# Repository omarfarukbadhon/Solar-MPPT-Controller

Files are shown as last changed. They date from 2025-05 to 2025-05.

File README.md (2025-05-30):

# Design and Development of a 1.5A MPPT Solar Charge Controller! 
Built around the LT3652, this compact system is optimized for 15W solar panels and 12V SLA batteries, offering efficient 3-stage charging with enhanced thermal and electrical protection.
Designed for harsh environments with: <br> 
✅ Reverse polarity and surge protection <br> 
✅ DIN-rail mountable compact PCBA (75×55 mm)

# 3D View of Solar MPPT Charge controller design 



# PCB Routing 



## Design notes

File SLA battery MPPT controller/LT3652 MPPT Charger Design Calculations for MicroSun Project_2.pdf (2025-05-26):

LT3652 MPPT Charger Design Calculations for MicroSun Project

### 1. Project Overview

This document outlines the design calculations for configuring the LT3652-based MPPT solar battery charger, targeting a 12V SLA battery and a 15W solar panel.

### 2. Charging Current Sense Resistor (R_SENSE)

Objective: Limit charging current to 1.5A maximum.

Formula:

R_SENSE = 0.1 / I_CHG(MAX)

Calculation:

R_SENSE = 0.1 / 1.5 = 0.0667 ohms

Recommended: Use standard value 0.068 ohm, 1% tolerance, ≥0.5W rated, low TCR.

### 3. How These Feedback Resistor Values Were Chosen (with LM234)

From the datasheet (Figure 9b), they used this design procedure:

Given:

- TC (temperature coefficient) = −19.8 mV/°C
- V_FLOAT (25°C) = 13.8 V
- R_SET = 2.4 kΩ for LM234
Step 1: Compute R_FB1

R_FB1 = −R_SET × (TC × 4405) = −2.4k × (−0.0198 × 4405) = 2.4k × 87.219 ≈ 209.3 kΩ

Designers approximated this to 210 kΩ or even 309 kΩ for tuning.

Step 2: Compute R_FB2

R_FB2 = R_FB1 / ((V_FLOAT + R_FB1 × (0.0674 / R_SET)) / V_FB − 1)

Where:

- V_FB = 3.3V (LT3652 internal reference)
- V_FLOAT = 13.8V (target float voltage)
- R_SET = 2.4kΩ
- R_FB1 = 309kΩ
Step 3: Adjust R_FB3 to make R_FB2 || R_FB3 ≈ 63.5 kΩ That matches the required divider to bring the VFB node to 3.3 V at the proper V_FLOAT.

### 4. VIN_REG Divider for MPPT (Input Voltage Regulation)

Objective: Hold solar panel input at ~17.6V (Vmp) for maximum power point tracking.

Formula:

R1/R2 = (V_IN / 2.7) - 1

Target V_IN: 17.6V

Calculation:

R1/R2 = (17.6 / 2.7) - 1 ≈ 5.52 Assume R2 = 100kΩ → R1 ≈ 552kΩ

Standard Value Selection:

- R1 = 549 kΩ
- R2 = 100 kΩ

Verification:

V_VIN_REG = 17.6 * 100 / (549 + 100) ≈ 2.71V ✅

This satisfies the LT3652 requirement to regulate at 2.7V.

### 5. Summary of Key Design Values

Parameter | Value
Max Charge Current | 1.5 A
R_SENSE | 0.068 Ω
Feedback Resistors | 309k, 174k, 100k
VIN_REG Divider | 549k, 100k

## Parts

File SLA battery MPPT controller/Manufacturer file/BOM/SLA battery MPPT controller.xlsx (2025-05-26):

Comment | Description | Designator | Footprint | LibRef | Quantity
1uF | 25V 1uF X5R ±10% 0805 Multilayer Ceramic Capacitors MLCC - SMD/SMT ROHS | C1 | C0805 | GRM216R61E105KA12D | 1
10uF | 35V 10uF X5R ±10% 1206 Multilayer Ceramic Capacitors MLCC - SMD/SMT ROHS | C2, C3 | C1206 | GRT31CR6YA106KE01L | 2
100uF | 100uF 25V 130mA@120Hz ±20% SMD,D8xL10.2mm Aluminum Electrolytic Capacitors - SMD ROHS | C4 | CAP-SMD_BD8.0-L8.3-W8.3-LS9.5-FD | EEEHC1E101P | 1
1N4148WS-7-F | 75V Independent Type 1.25V@150mA 4ns 150mA SOD-323 Switching Diodes ROHS | D1, D5 | SOD-323_L1.8-W1.3-LS2.5-RD | 1N4148WS-7-F | 2
MMSZ5234BT1G | Independent Type 5.89V~6.51V 500mW 6.2V SOD-123 Zener Diodes ROHS | D2 | SOD-123_L2.8-W1.8-LS3.7-RD | MMSZ5234BT1G | 1
V8PAL45-M3/I | 45V 4A 570mV@8A DO-221BC(SMPA) Schottky Diodes ROHS | D3, D4 | DO-221BC_L4.3-W2.7-LS5.3-RD | V8PAL45-M3/I | 2
0437003.WR | 50A SMD Fuse 3A 32V 1206 Disposable fuses ROHS | F1 | F1206 | Fuse | 1
22 μH | WE-PD SMT Power Inductor, size 7345R, 22 μH, 1.41 A, 110 mΩ | L1 | WE-PD_7345R | 7447779122 | 1
LTST-C170KRKT | 20mA 54mcd Colorless Transparent Lens -55℃~+85℃ 631nm Red 130° 75mW 2V 0805 LED Indication - Discrete ROHS | LED1, LED2 | LED0805-R-RD | LTST-C170KRKT | 2
WJ128V-5.0-2P | 1x2P 20A -40℃~+105℃ 250V Green 12~22 Direct Insert 5mm 2.5 1 2 Plugin,P=5mm Screw Terminal Blocks ROHS | P1, P2 | CONN-TH_2P-P5.00_WJ128V-5.0-2P | WJ128V-5.0-2P | 2
562kΩ | 0.125W Thick Film Resistors ±100ppm/℃ ±1% 562kΩ 0805 Chip Resistor - Surface Mount ROHS | R1 | R0805 | ERJ6ENF5623V | 1
0.068Ω | 0.125W Thick Film Resistors 300V ±600ppm/℃ ±5% 0.068Ω 0805 Chip Resistor - Surface Mount ROHS | R2 | R0805 | FRL0805JR068TS | 1
309kΩ | 309kΩ 0805 Chip Resistor 0.125W Thick Film Resistors ±100ppm/℃ ±1% - Surface Mount ROHS | R3 | R0805 | ERJ6ENF3093V | 1
10kΩ | 10kΩ 0805 Chip Resistor 0.2W Thick Film Resistors 200V ±50ppm/℃ ±0.1% - Surface Mount ROHS | R4, R5 | R0805 | ERJPB6B1002V | 2
100kΩ | 100kΩ 0805 Chip Resistor 0.125W Thick Film Resistors ±100ppm/℃ ±1% - Surface Mount ROHS | R6, R7 | R0805 | ERJ6ENF1003V | 2
1MΩ | 1MΩ 0805 Chip Resistor 0.5W Thick Film Resistors ±5% ±200ppm/℃ - Surface Mount ROHS | R8 | R0805 | ERJP06J105V | 1
174kΩ | 174kΩ 0805 Chip Resistor 0.125W Thick Film Resistors ±100ppm/℃ ±1% - Surface Mount ROHS | R9 | R0805 | ERJ6ENF1743V | 1
LT3652EDD#PBF | 4.95V~32V Multi-Chemical 1~4 2A DFN-12(3x3) Battery Management ROHS | U1 | DFN-12_L3.0-W3.0-P0.50-LS3.0-BL-EP | LT3652EDD#PBF | 1

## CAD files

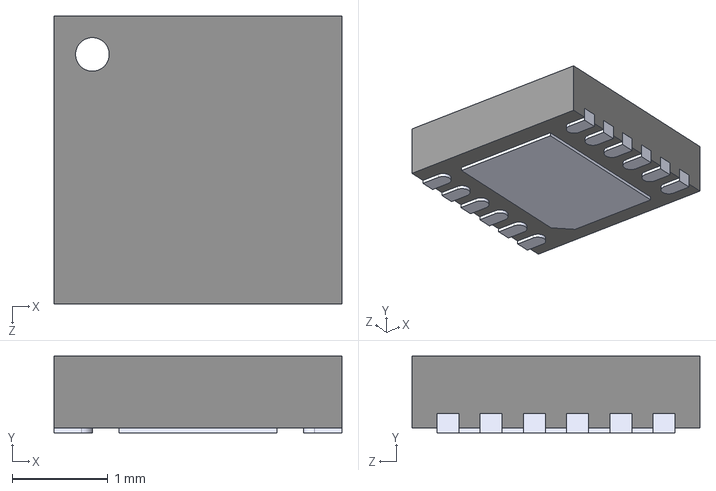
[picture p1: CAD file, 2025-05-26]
3D/LT3652EDD#PBF.STEP
3.00 x 0.8 x 3.00 mm

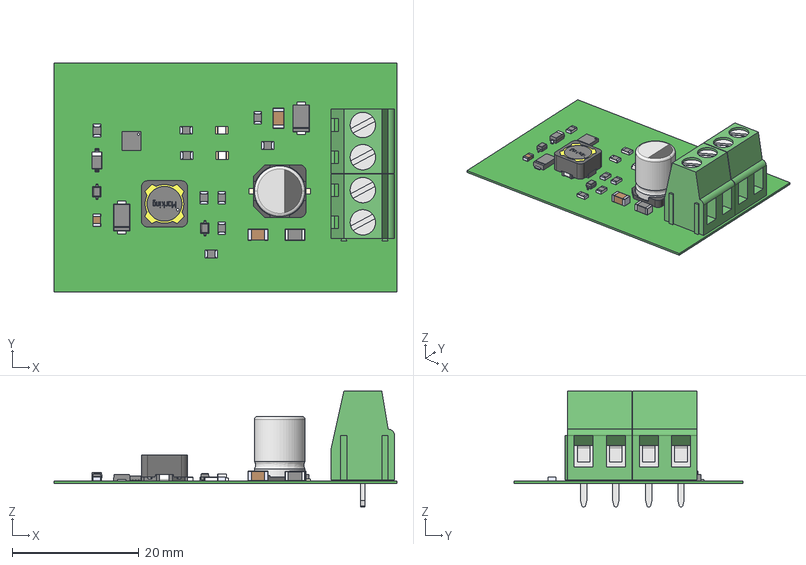
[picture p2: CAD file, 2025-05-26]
SLA battery MPPT controller/Manufacturer file/PCB.step
54.1 x 36.1 x 18.3 mm
LT3652EDD#PBF
R805 x 9
Pin (1) (19) x 2
Tornillo (1) (19) x 2
Cubo interno (1) (19) x 2
Pin (1) (1) (18) x 2
Tornillo (1) (1) (18) x 2
Cubo interno (1) (1) (18) x 2
Pin (1) (11) x 2
Tornillo (1) (11) x 2
Cubo interno (1) (11) x 2
Pin (1) (1) (10) x 2
Tornillo (1) (1) (10) x 2
Cubo interno (1) (1) (10) x 2
LED x 2
Boden
Pins x 2
Kern x 3
Schirmring
Kleber
Fuse
1N4148WS-7-F x 2
V8PAL45-M3_I x 2
MMSZ5234BT1G
AEC cap
C1210 x 2
C805

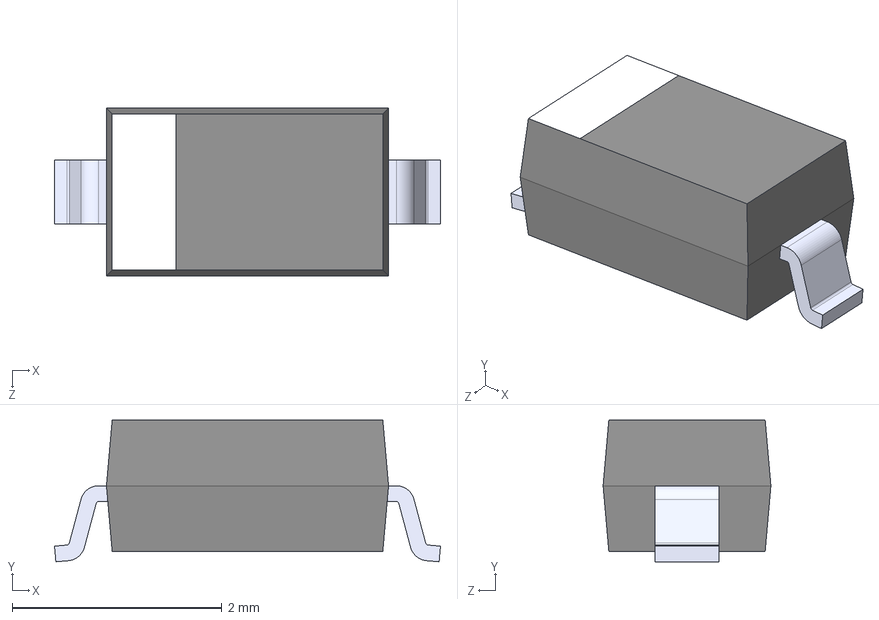
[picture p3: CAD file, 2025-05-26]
3D/MMSZ5234BT1G.STEP
3.68 x 1.35 x 1.60 mm

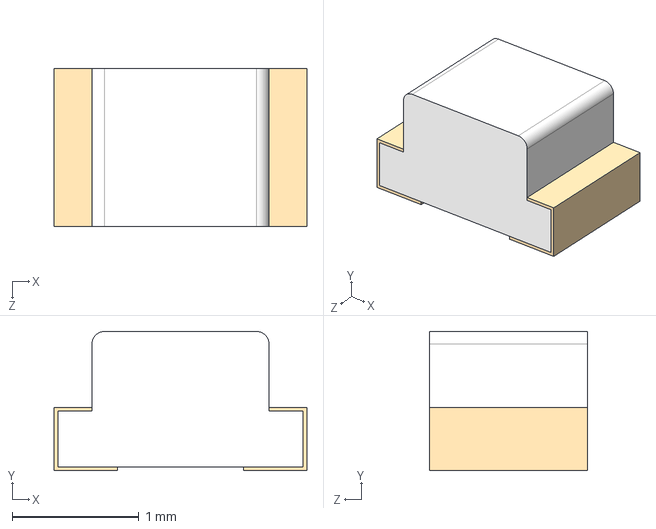
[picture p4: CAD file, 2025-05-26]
3D/LED.STEP
2.00 x 1.10 x 1.25 mm

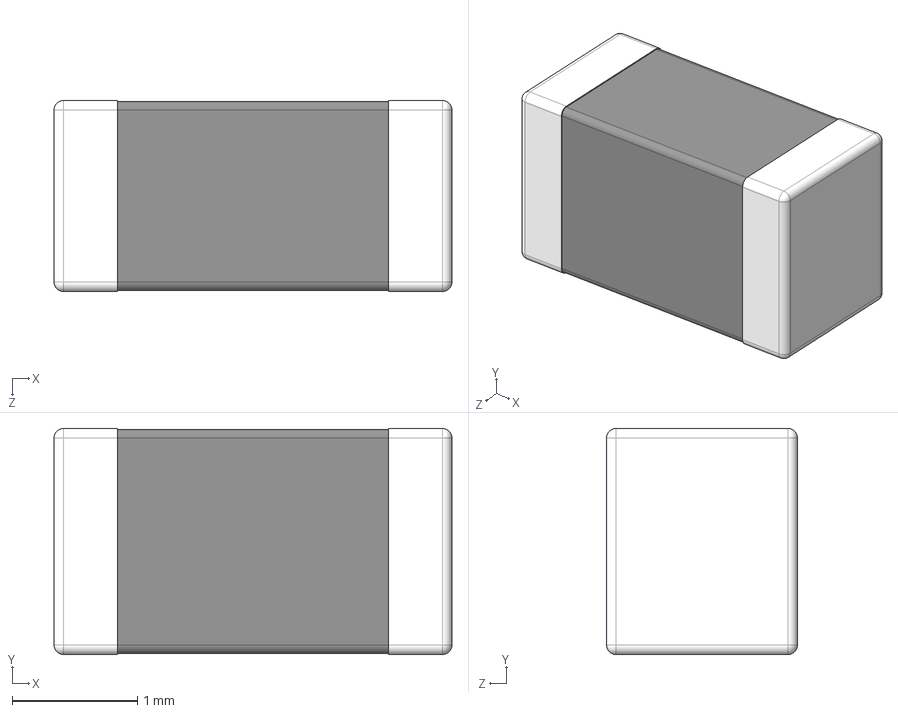
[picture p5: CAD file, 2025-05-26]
3D/Fuse.STEP
3.18 x 1.80 x 1.52 mm

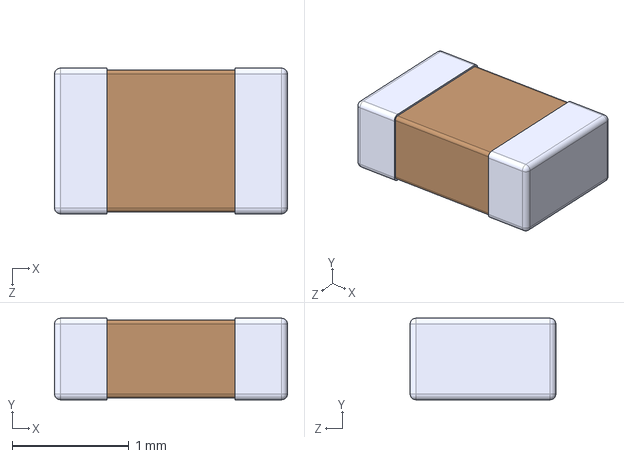
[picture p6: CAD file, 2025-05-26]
3D/C805.STEP
2.00 x 0.7 x 1.25 mm

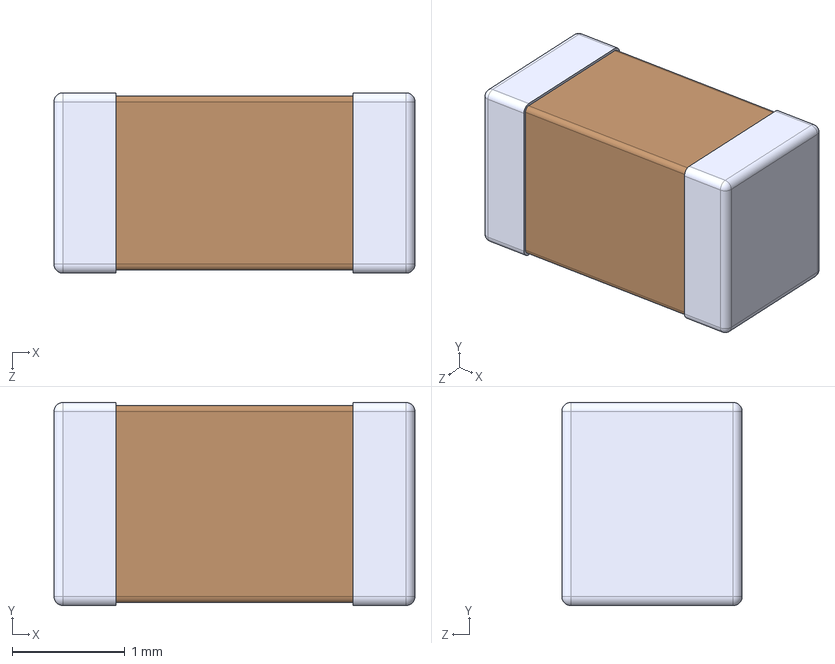
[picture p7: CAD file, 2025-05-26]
3D/C1210.STEP
3.20 x 1.80 x 1.60 mm

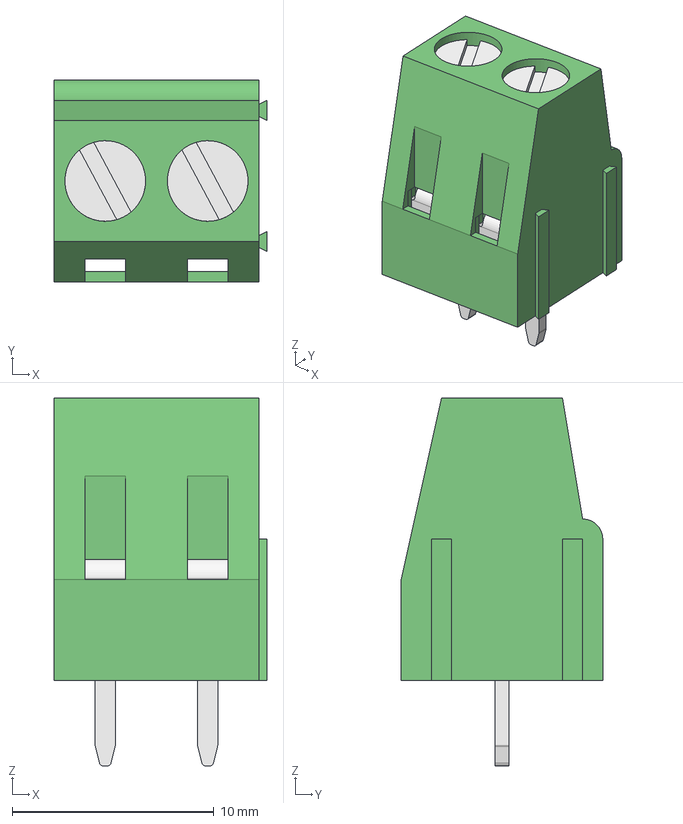
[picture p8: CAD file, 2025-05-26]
3D/2er Terminal Block.step
10.6 x 10.0 x 18.2 mm
Pin (1) (19)
Tornillo (1) (19)
Cubo interno (1) (19)
Pin (1) (1) (18)
Tornillo (1) (1) (18)
Cubo interno (1) (1) (18)
Pin (1) (11)
Tornillo (1) (11)
Cubo interno (1) (11)
Pin (1) (1) (10)
Tornillo (1) (1) (10)
Cubo interno (1) (1) (10)

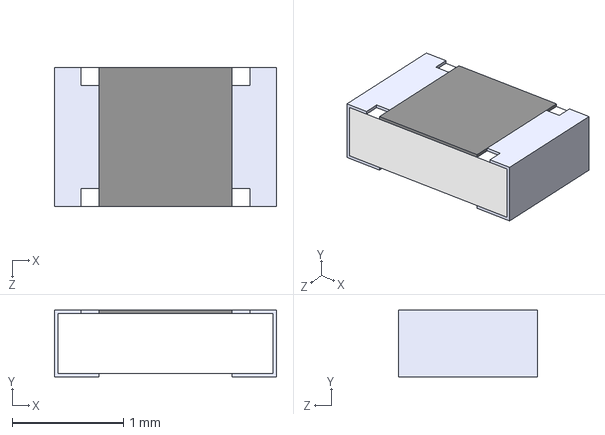
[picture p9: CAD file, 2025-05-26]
3D/R805.STEP
2.00 x 0.6 x 1.25 mm

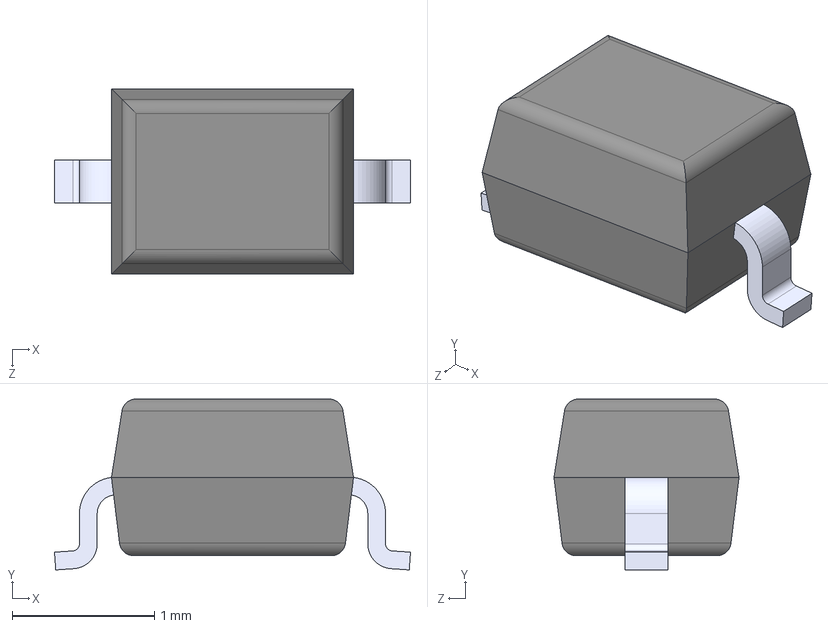
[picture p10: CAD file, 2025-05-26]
3D/1N4148WS-7-F.STEP
2.50 x 1.20 x 1.30 mm

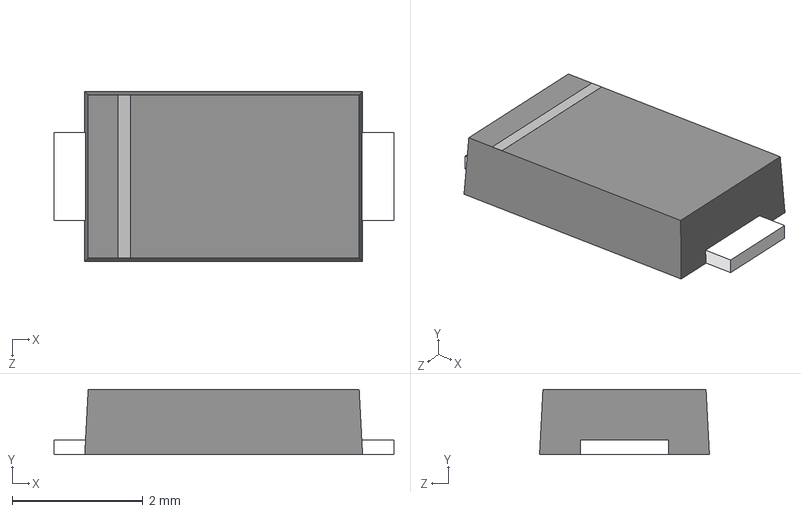
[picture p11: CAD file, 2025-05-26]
3D/V8PAL45-M3_I.STEP
5.20 x 1.00 x 2.60 mm

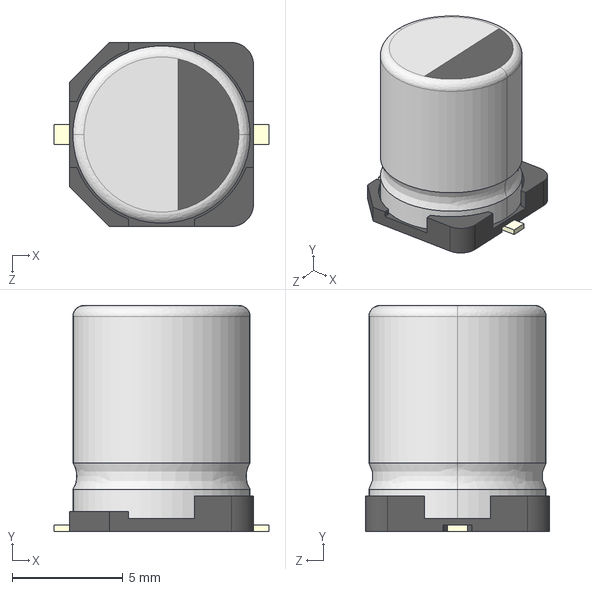
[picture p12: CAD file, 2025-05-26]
3D/AEC cap.STEP
9.70 x 10.2 x 8.30 mm
